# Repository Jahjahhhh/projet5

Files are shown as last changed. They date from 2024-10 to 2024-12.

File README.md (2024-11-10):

# Standing desk projet

```/projet5/table-2/```: KiCAD files<br>
```/projet/arduino/projet5```: Arduino files

### Hardware
- 2x 12VDC Linear Actuators (12")
- ESP32 (To access the web and gather info for date, time, weather)
- Dual H-Bridge motor driver (each linear actuator pulls 5 A continuous)
- LED strip (5V Adressable LEDs)
- USB charging hub (2x USB-A & 1x USB-C)
- Ultrasonic sensor to detect when you go from standing to sitting
- MPU6050 (3 axis gyro and accelerometer) to measure the flatness of the table (in case the linear actuators are out of sync)
- 4 Debounced push buttons
- 1 SPDT toggle switch to control linear actuators (ON - OFF - ON)
- 1.8" OLED SPI display

### Schematic
![alt text](https://github.com/Jahjahhhh/projet5/blob/main/schematic.png?raw=true)
<br>

### PCB
![alt text](https://github.com/Jahjahhhh/projet5/blob/main/pcb.png?raw=true)

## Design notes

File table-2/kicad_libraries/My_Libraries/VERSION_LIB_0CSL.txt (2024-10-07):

VERSION 124
de 0CSL_D1_V1  POUR KiCad V6

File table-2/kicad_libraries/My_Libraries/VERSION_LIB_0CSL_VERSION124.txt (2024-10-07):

Ce fichier indique par son nom même dans quelle version de quelle librairie il se trouve.

André Gauthier 6 octobre 2023 pour la version 124 LA DERNIERE DE A 2023!

   La version 86 est le première version permettant 
          de réaliser le SHIELD Versions 2022 et 2023.

   La version 80 est la première version des lib du CÉGEP pour KiCadV6
     nombreuses corrections de courtyard et de pointeurs pour modeles 3D   

L'utilité de ce fichier est de savoir quelle version de la librairie est la dernière installée.

Ce fichier est utilisé de concert avec le fichier
VERSION_LIB_0CSL.TXT  qui pour sa part contient le numéro de version.

Si on a copié de multiples versions de la librairie au même endroit, comme on doit normalement 
le faire pour avoir les nouvelles pièces du cours de projet, le dernier chiffre
apparent dans le nom de ce fichier doit être la dernière version installée
et on devrait retrouver cette valeur dans le fichier
VERSION_LIB_0CSL.TXT

Cette maniére de faire a été inspirée le 12 septembre 2020 par Madame Sydney Athans qui souhaitait 
trouver une méthode de savoir quelle était la librairie installée.

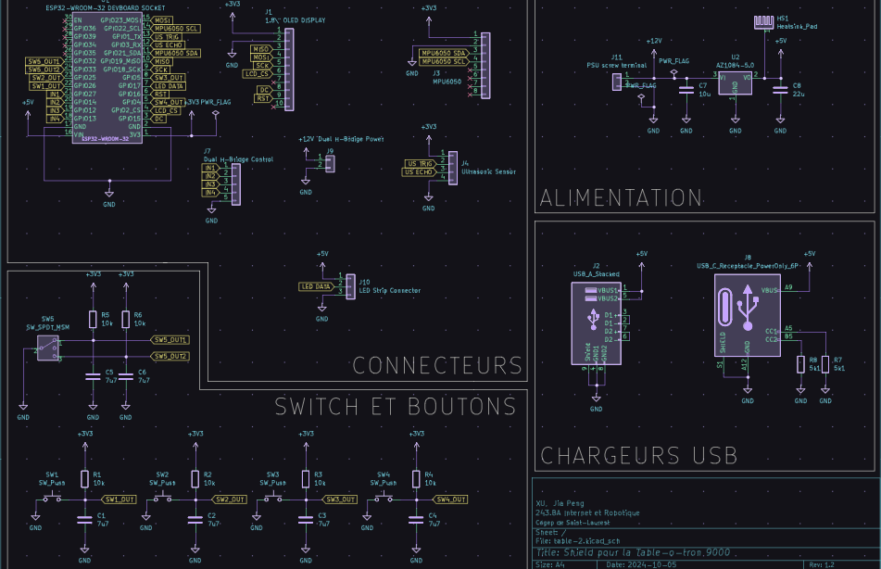
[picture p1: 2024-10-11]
schematic.png

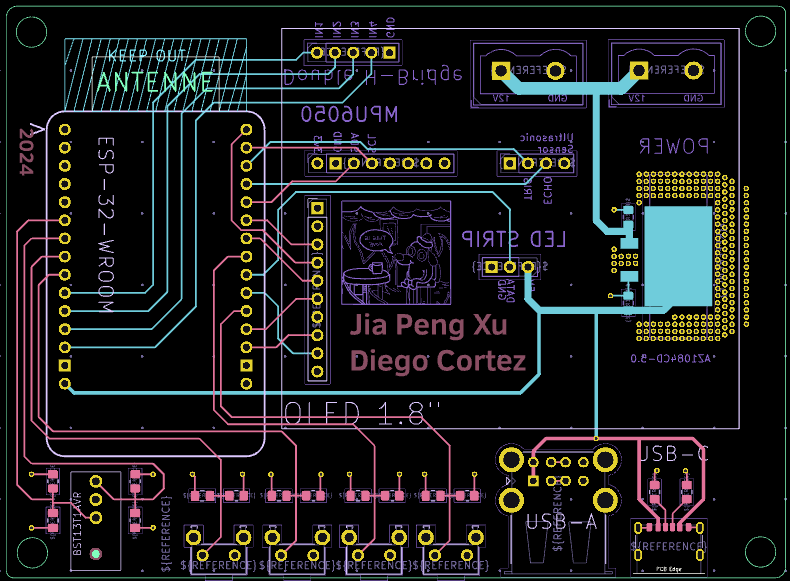
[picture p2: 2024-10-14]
pcb.png

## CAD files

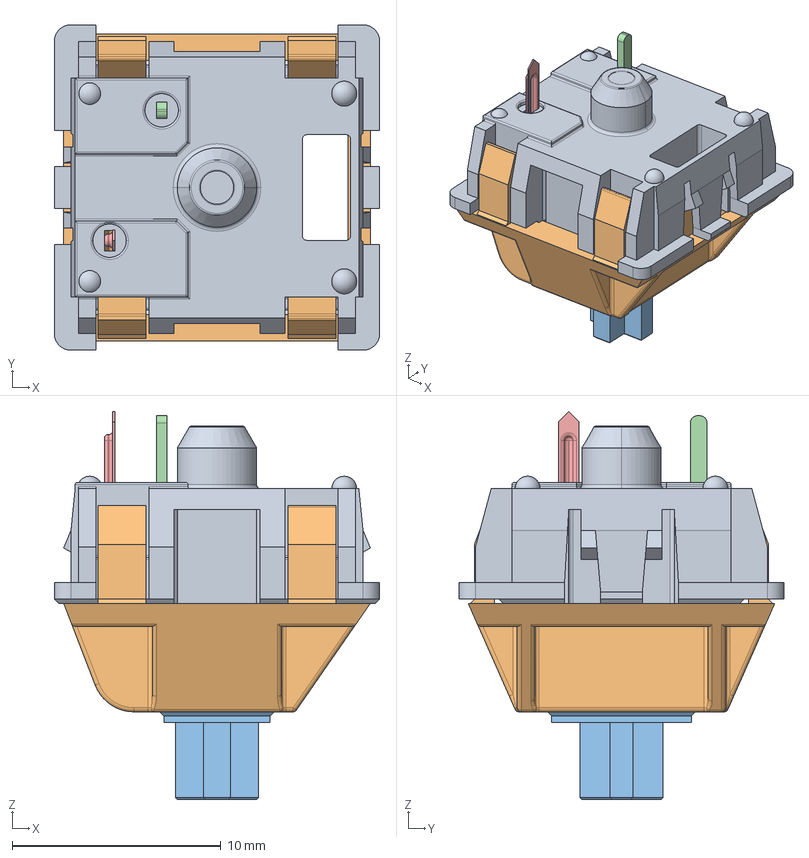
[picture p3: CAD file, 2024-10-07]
table-2/kicad_libraries/My_Libraries/CHERRY_asm_PLATE.stp
15.6 x 15.6 x 18.6 mm
MX_DOWN
MX_UP
UP_MX
MX_PIN
MX_SPRING
MX_CLICK

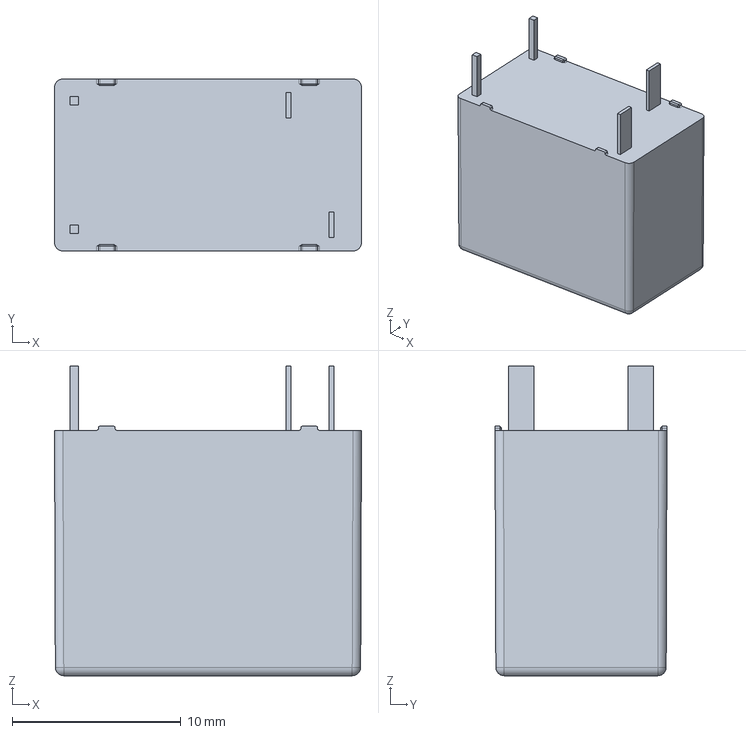
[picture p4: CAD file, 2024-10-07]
table-2/kicad_libraries/My_Libraries/c-1-2071556-1-a-3d.stp
18.2 x 10.2 x 18.4 mm

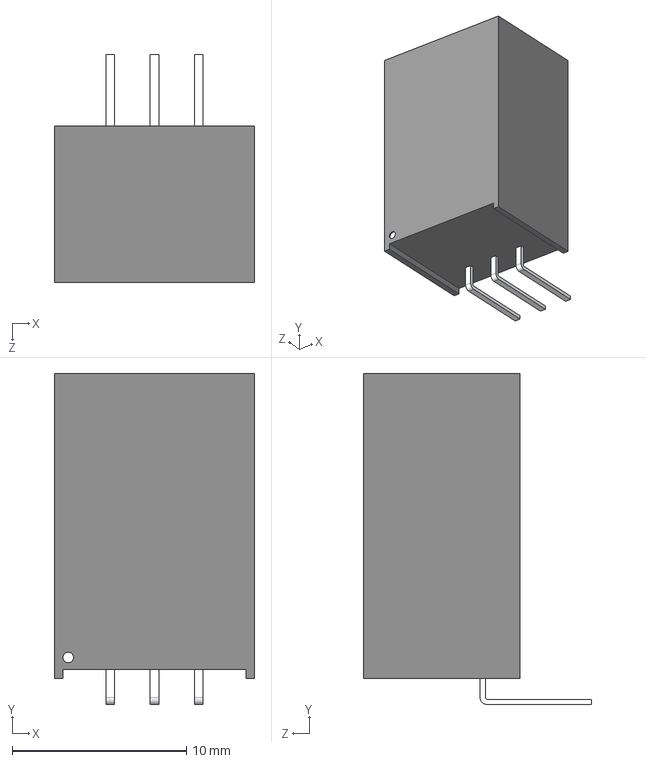
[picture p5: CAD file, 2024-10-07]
table-2/kicad_libraries/My_Libraries/CUI_V7805-1000R.step
11.5 x 19.0 x 13.1 mm

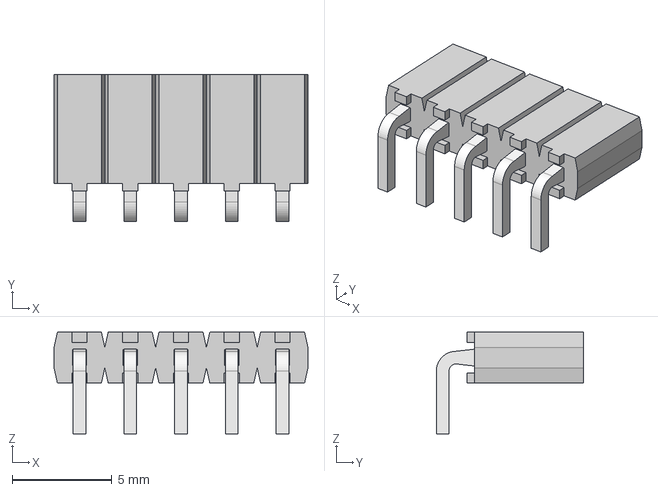
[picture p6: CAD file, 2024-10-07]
table-2/kicad_libraries/My_Libraries/Header_cassable_5Short_pins__simpleAG2.step
12.7 x 7.37 x 5.08 mm
_SSA-132-W-T-RA_t
_SSA-132-W-T-RA_p

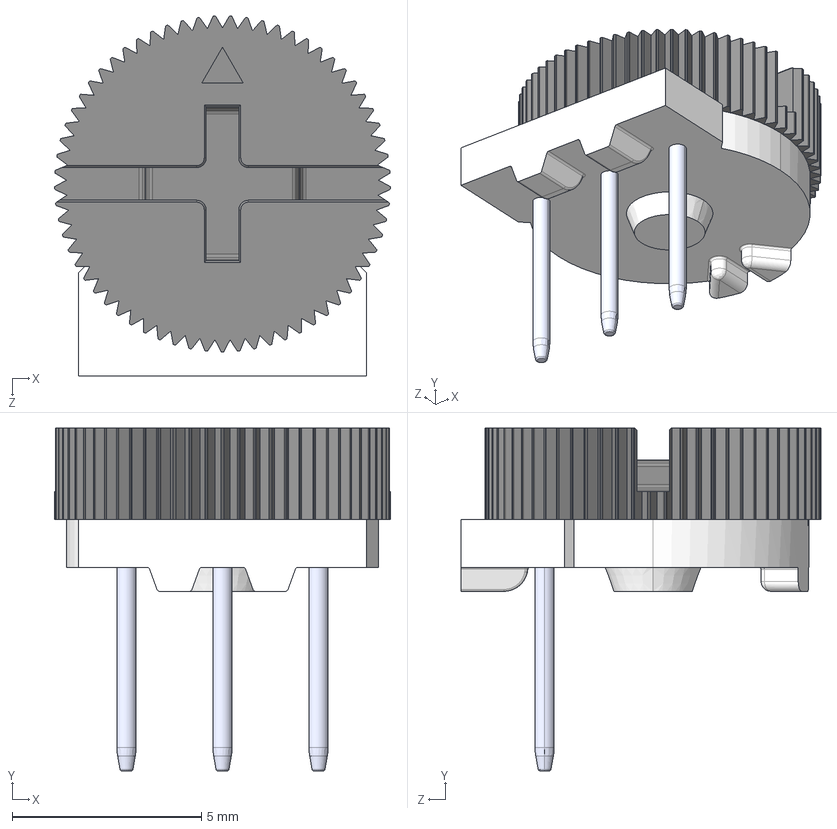
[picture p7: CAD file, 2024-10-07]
table-2/kicad_libraries/My_Libraries/POT_3352T-1-103LF.STEP
8.89 x 9.07 x 9.52 mm

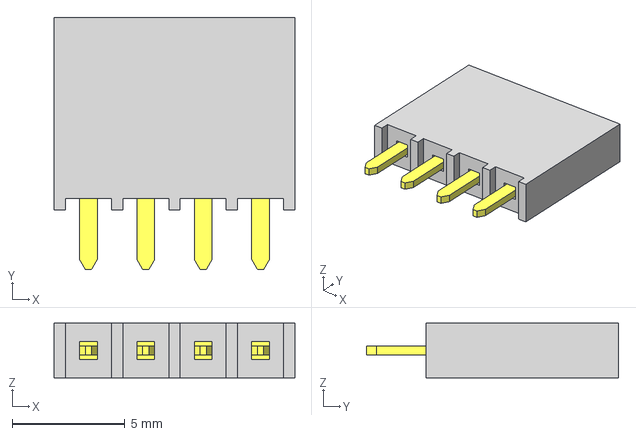
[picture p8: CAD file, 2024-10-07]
table-2/kicad_libraries/My_Libraries/Header4F_100mils.step
10.7 x 11.2 x 2.41 mm
_T1SSW-110-01-F-S
_P2SSW-110-01-F-S

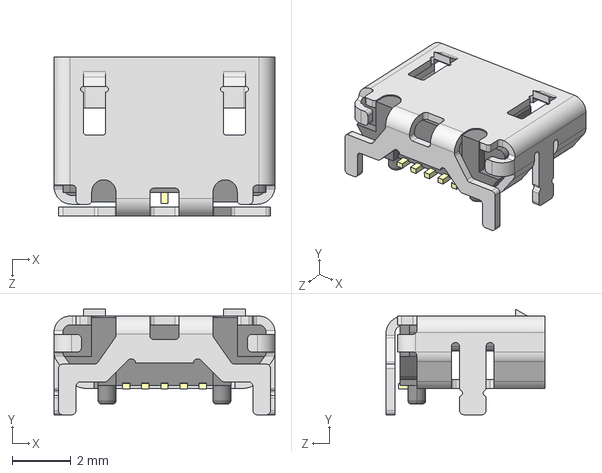
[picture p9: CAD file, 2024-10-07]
table-2/kicad_libraries/My_Libraries/KMMX-BSMT35S-BTR_A.STEP
7.50 x 3.58 x 5.40 mm

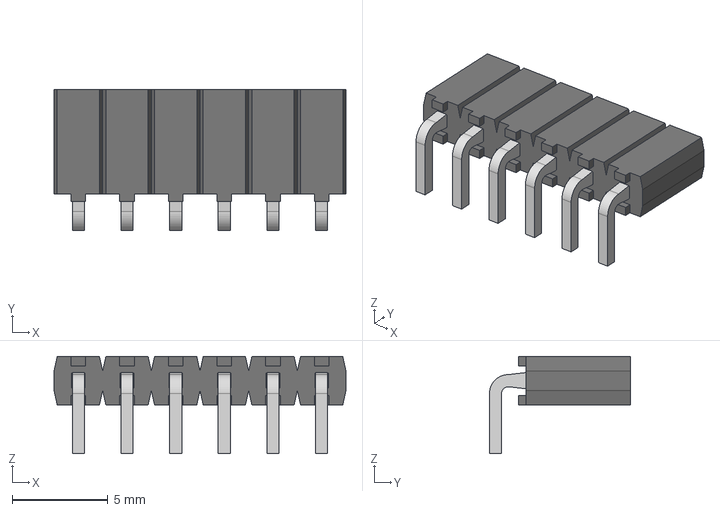
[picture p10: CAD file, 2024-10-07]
table-2/kicad_libraries/My_Libraries/Header_Cassable_6Short-pins_AG3.step
15.2 x 7.37 x 5.08 mm
_SSA-132-W-T-RA_t
_SSA-132-W-T-RA_p

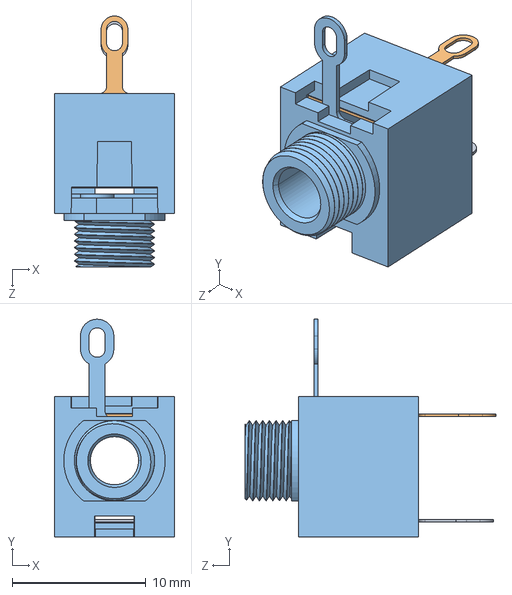
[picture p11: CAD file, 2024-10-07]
table-2/kicad_libraries/My_Libraries/KYCON3501.STEP
9.00 x 16.3 x 18.8 mm

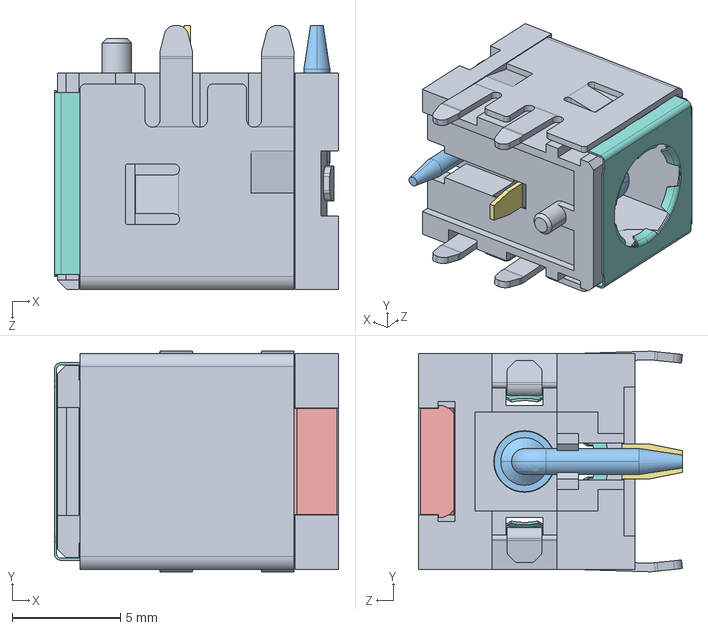
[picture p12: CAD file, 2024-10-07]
table-2/kicad_libraries/My_Libraries/CUI_DEVICES_PJ-082BH.step
13.1 x 10.2 x 12.2 mm

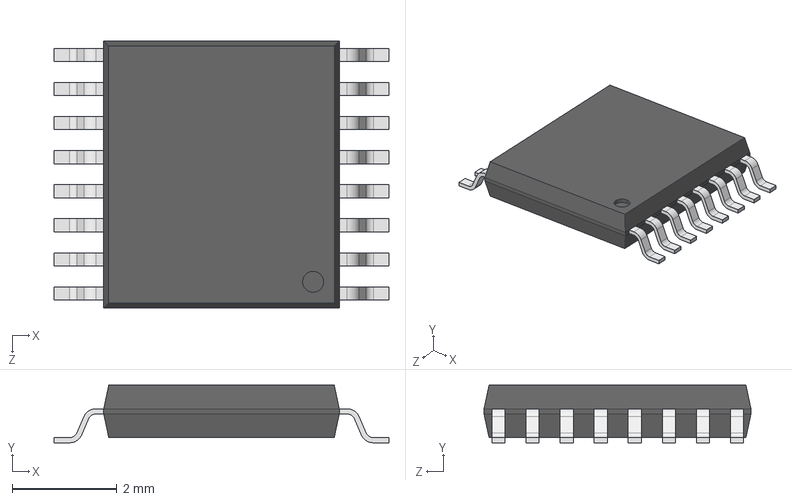
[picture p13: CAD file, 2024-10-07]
table-2/kicad_libraries/My_Libraries/TSSOP-16 5_1x4_4.STEP
6.40 x 1.10 x 5.10 mm
pin_TSSOP_tssop_1 x 16
body_TSSOP_TSSOP_5.1x4.5_1

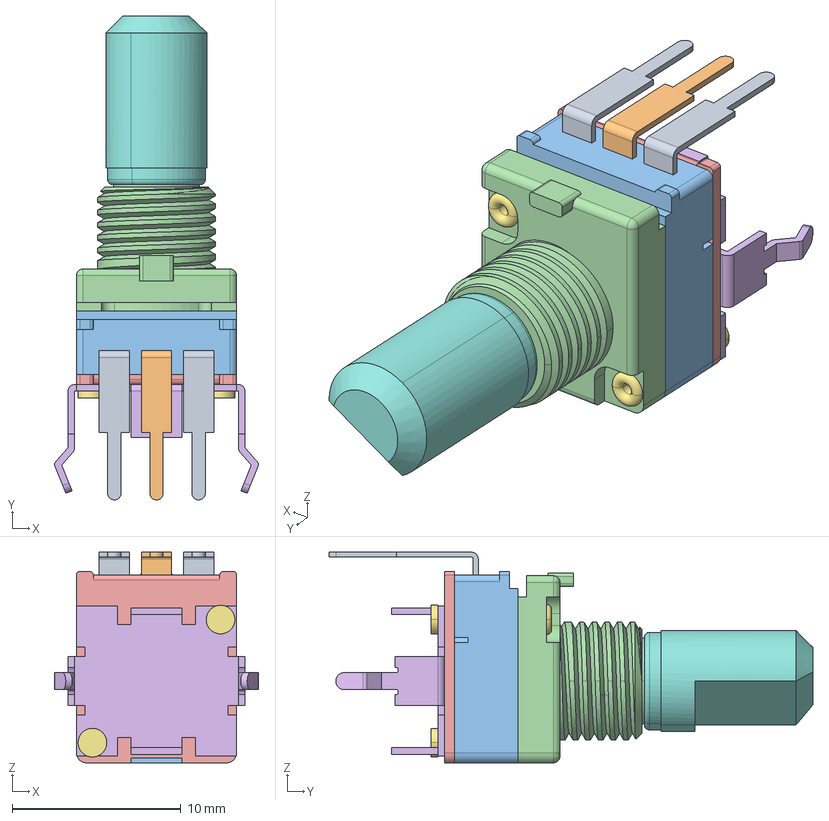
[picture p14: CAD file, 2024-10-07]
table-2/kicad_libraries/My_Libraries/P0915N-FC15AR50K.stp
12.1 x 28.7 x 12.5 mm

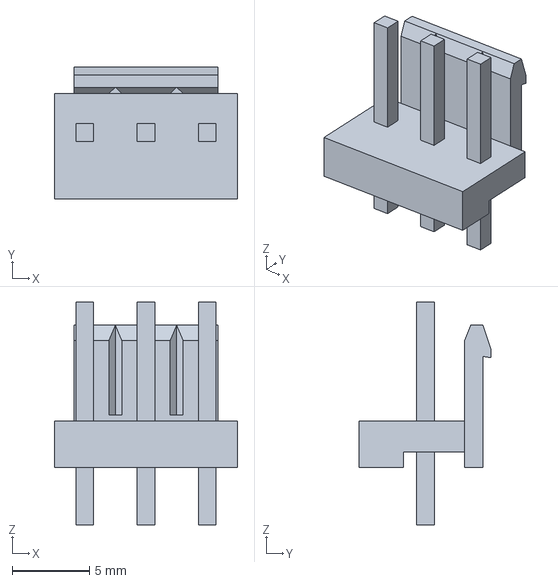
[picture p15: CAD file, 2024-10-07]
table-2/kicad_libraries/My_Libraries/1-1318300-3.stp
11.8 x 8.50 x 14.4 mm

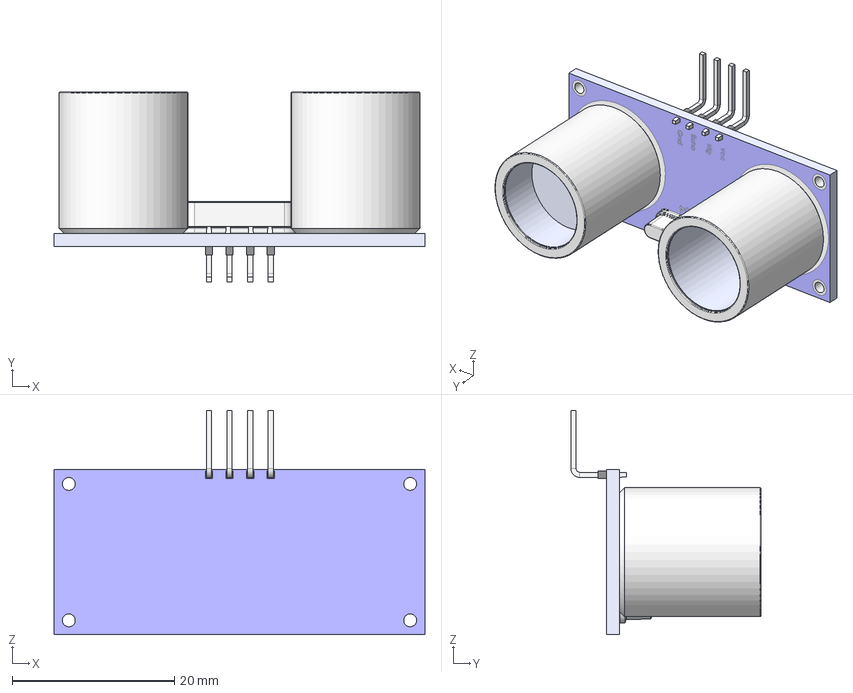
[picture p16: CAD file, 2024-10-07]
table-2/kicad_libraries/My_Libraries/HC_SR04_AG.step
45.7 x 23.4 x 27.6 mm

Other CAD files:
table-2/kicad_libraries/My_Libraries/Header_cassable_4Short_pins__simpleAG2 v1.step
table-2/kicad_libraries/My_Libraries/SOT_223_5.STEP
table-2/kicad_libraries/My_Libraries/cree xlamp_xp_e.stl
table-2/kicad_libraries/My_Libraries/1-1318300-2.stp
table-2/kicad_libraries/My_Libraries/1-1825027-1_Bouton_Bleu v1.step
table-2/kicad_libraries/My_Libraries/10067847_001RLF.stp
table-2/kicad_libraries/My_Libraries/1301_9503_3.STEP
table-2/kicad_libraries/My_Libraries/2908-05WB-MGAG.step
table-2/kicad_libraries/My_Libraries/3006_MAX98357.step
table-2/kicad_libraries/My_Libraries/3214J.stp
table-2/kicad_libraries/My_Libraries/395430202.stp
table-2/kicad_libraries/My_Libraries/530480260.stp
table-2/kicad_libraries/My_Libraries/530480910.stp
table-2/kicad_libraries/My_Libraries/61201021621--3DModel-STEP-56544.STEP
table-2/kicad_libraries/My_Libraries/62684_502100AHLF_A.step
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

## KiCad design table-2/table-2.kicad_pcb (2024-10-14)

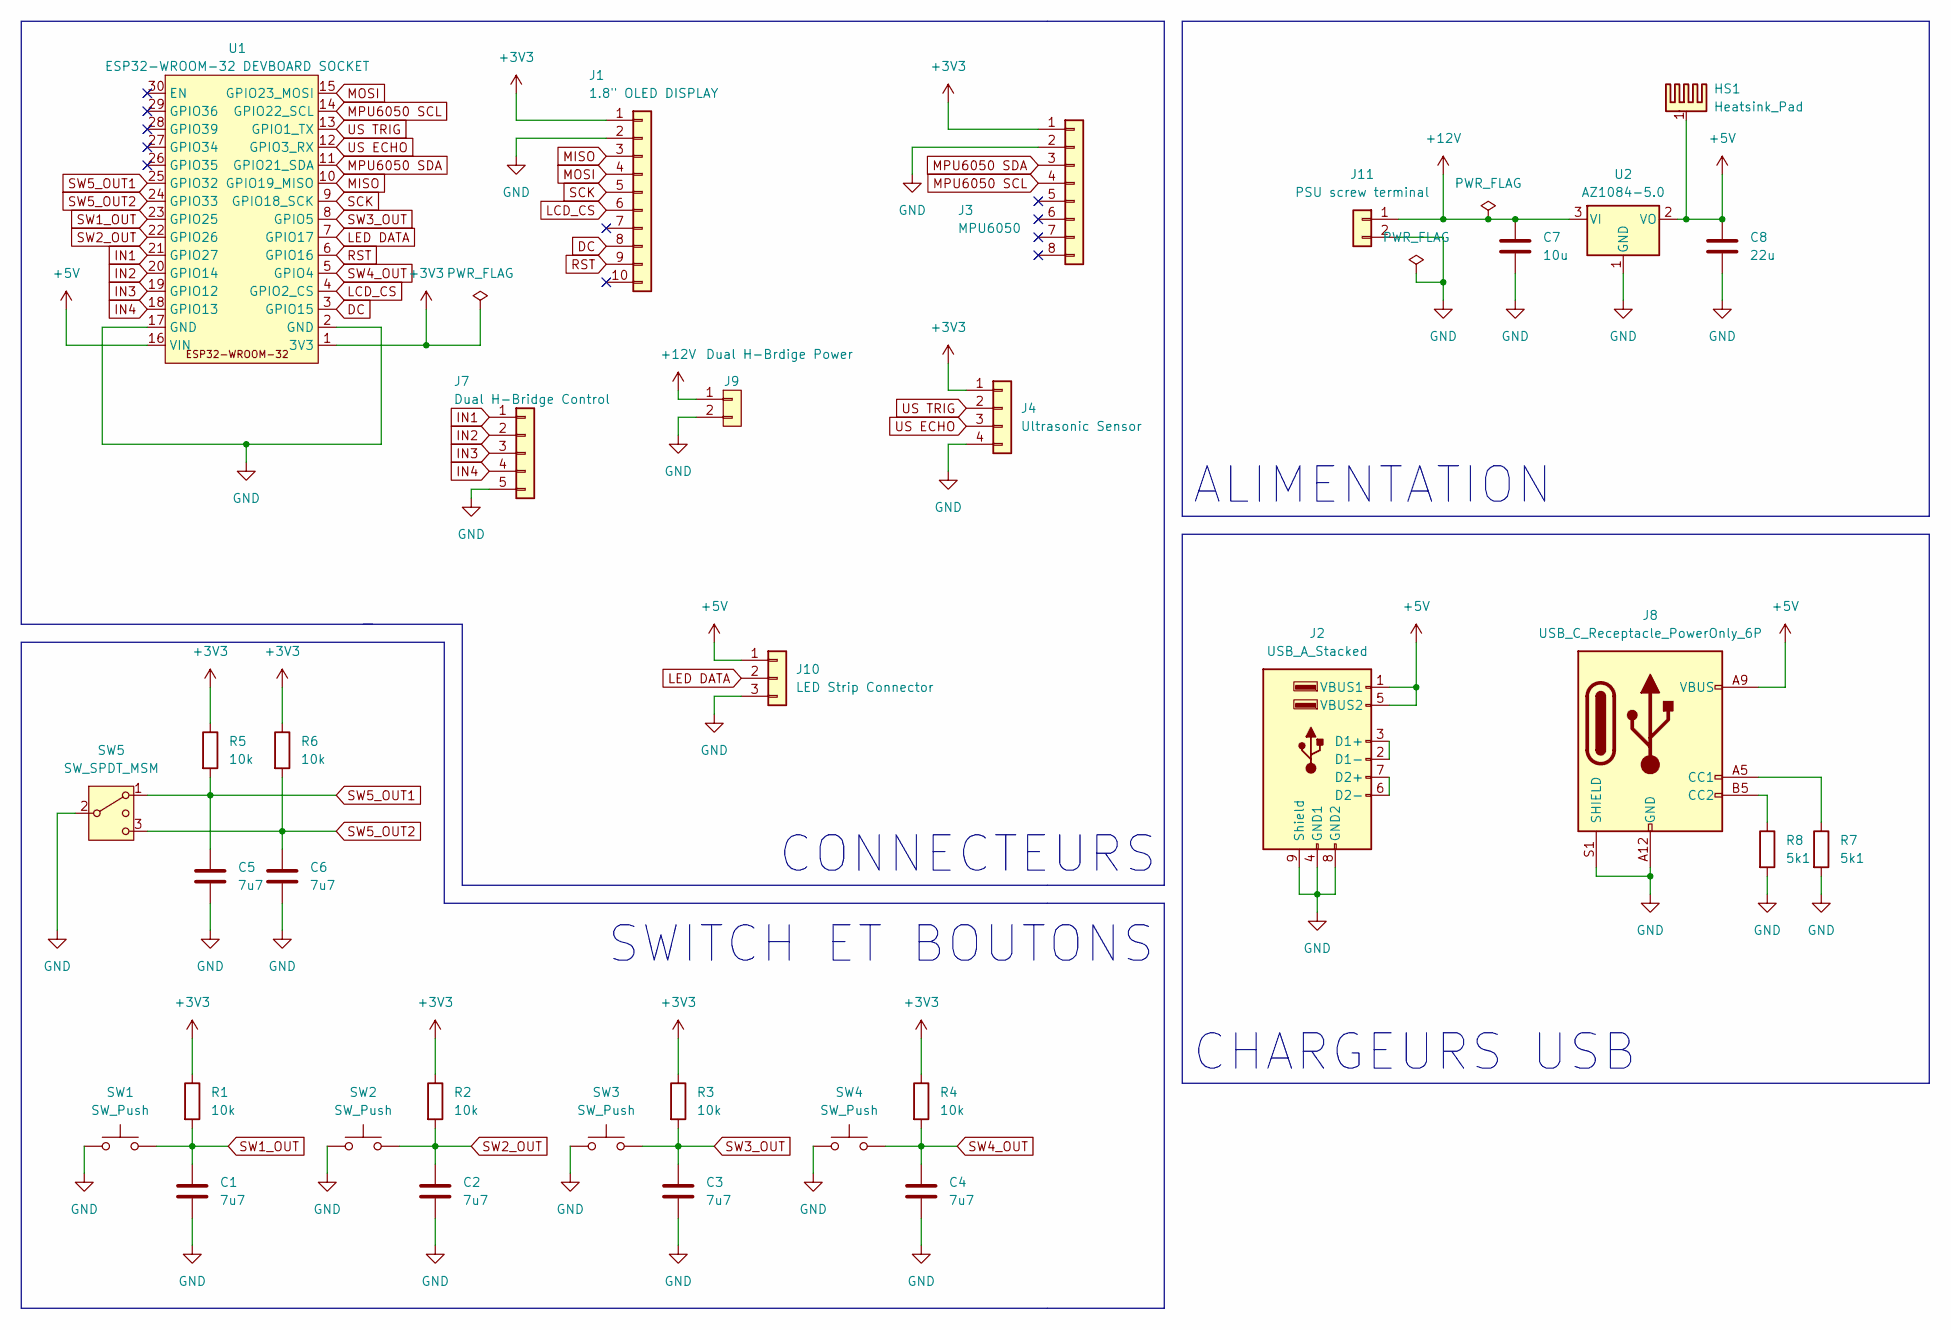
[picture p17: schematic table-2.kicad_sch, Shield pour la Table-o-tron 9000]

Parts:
C1, C2, C3, C4, C5, C6: 7u7; C_0805_2012Metric_Pad1.18x1.45mm_HandSolder
C7: 10u; C_0805_2012Metric_Pad1.18x1.45mm_HandSolder
C8: 22u; C_0805_2012Metric_Pad1.18x1.45mm_HandSolder
HS1: Heatsink_Pad; HEATSINK_573100D00000G
J1: 1.8" OLED DISPLAY; PinHeader_1x10_P2.54mm_Vertical
J2: USB_A_Stacked; USB_A_CUI_UJ2-ADH-TH_Horizontal_Stacked
J3: MPU6050; PinHeader_1x08_P2.54mm_Vertical
J4: Ultrasonic Sensor; PinHeader_1x04_P2.54mm_Vertical
J7: Dual H-Bridge Control; PinHeader_1x05_P2.54mm_Vertical
J8: USB_C_Receptacle_PowerOnly_6P; USB_C_Receptacle_GCT_USB4125-xx-x-0190_6P_TopMnt_Horizontal
J9: Dual H-Brdige Power; TerminalBlock_Wuerth_691311400102_P7.62mm; Manufacturer Part Number 0530480260
J10: LED Strip Connector; PinHeader_1x03_P2.54mm_Vertical
J11: PSU screw terminal; TerminalBlock_Wuerth_691311400102_P7.62mm
R1, R2, R3, R4, R5, R6: 10k; R_0805_2012Metric_Pad1.20x1.40mm_HandSolder
R7, R8: 5k1; R_0805_2012Metric_Pad1.20x1.40mm_HandSolder
SW1, SW2, SW3, SW4: SW_Push; Tactile_90_TE
SW5: SW_SPDT_MSM; BST13T1AVR
U1: ESP32-WROOM-32 DEVBOARD SOCKET; ESP32_WROOM_32
U2: AZ1084-5.0; AZ1084CD-5.0TRG1

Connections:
+3V3: J1.1, J3.1, J4.1, R1.1, R2.1, R3.1, R4.1, R5.1, R6.1, U1.1 (3V3)
+5V: C8.1, HS1.1, J2.1 (VBUS1), J2.5 (VBUS2), J8.A9 (VBUS), J8.B9 (VBUS), J10.1, U1.16 (VIN), U2.2 (VO)
+12V: C7.1, J9.1, J11.1, U2.3 (VI)
DC: J1.8, U1.3 (GPIO15)
GND: C1.2, C2.2, C3.2, C4.2, C5.2, C6.2, C7.2, C8.2, J1.2, J2.4 (GND1), J2.8 (GND2), J2.9 (Shield), J3.2, J4.4, J7.5, J8.A12 (GND), J8.B12 (GND), J8.S1 (SHIELD), J9.2, J10.3, J11.2, R7.2, R8.2, SW1.1, SW2.1, SW3.1, SW4.1, SW5.2 (3), U1.2 (GND), U1.17 (GND), U2.1 (GND)
IN1: J7.1, U1.21 (GPIO27)
IN2: J7.2, U1.20 (GPIO14)
IN3: J7.3, U1.19 (GPIO12)
IN4: J7.4, U1.18 (GPIO13)
LCD_CS: J1.6, U1.4 (GPIO2_CS)
LED DATA: J10.2, U1.7 (GPIO17)
MISO: J1.3, U1.10 (GPIO19_MISO)
MOSI: J1.4, U1.15 (GPIO23_MOSI)
MPU6050 SCL: J3.4, U1.14 (GPIO22_SCL)
MPU6050 SDA: J3.3, U1.11 (GPIO21_SDA)
unnamed: J2.2 (D1-), J2.3 (D1+)
unnamed: J2.6 (D2-), J2.7 (D2+)
unnamed: J8.A5 (CC1), R7.1
unnamed: J8.B5 (CC2), R8.1
RST: J1.9, U1.6 (GPIO16)
SCK: J1.5, U1.9 (GPIO18_SCK)
SW1_OUT: C1.1, R1.2, SW1.2, U1.23 (GPIO25)
SW2_OUT: C2.1, R2.2, SW2.2, U1.22 (GPIO26)
SW3_OUT: C3.1, R3.2, SW3.2, U1.8 (GPIO5)
SW4_OUT: C4.1, R4.2, SW4.2, U1.5 (GPIO4)
SW5_OUT1: C5.1, R5.2, SW5.1, U1.25 (GPIO32)
SW5_OUT2: C6.1, R6.2, SW5.3 (4), U1.24 (GPIO33)
US ECHO: J4.3, U1.12 (GPIO3_RX)
US TRIG: J4.2, U1.13 (GPIO1_TX)

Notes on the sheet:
CONNECTEURS
CHARGEURS USB
SWITCH ET BOUTONS
ALIMENTATION

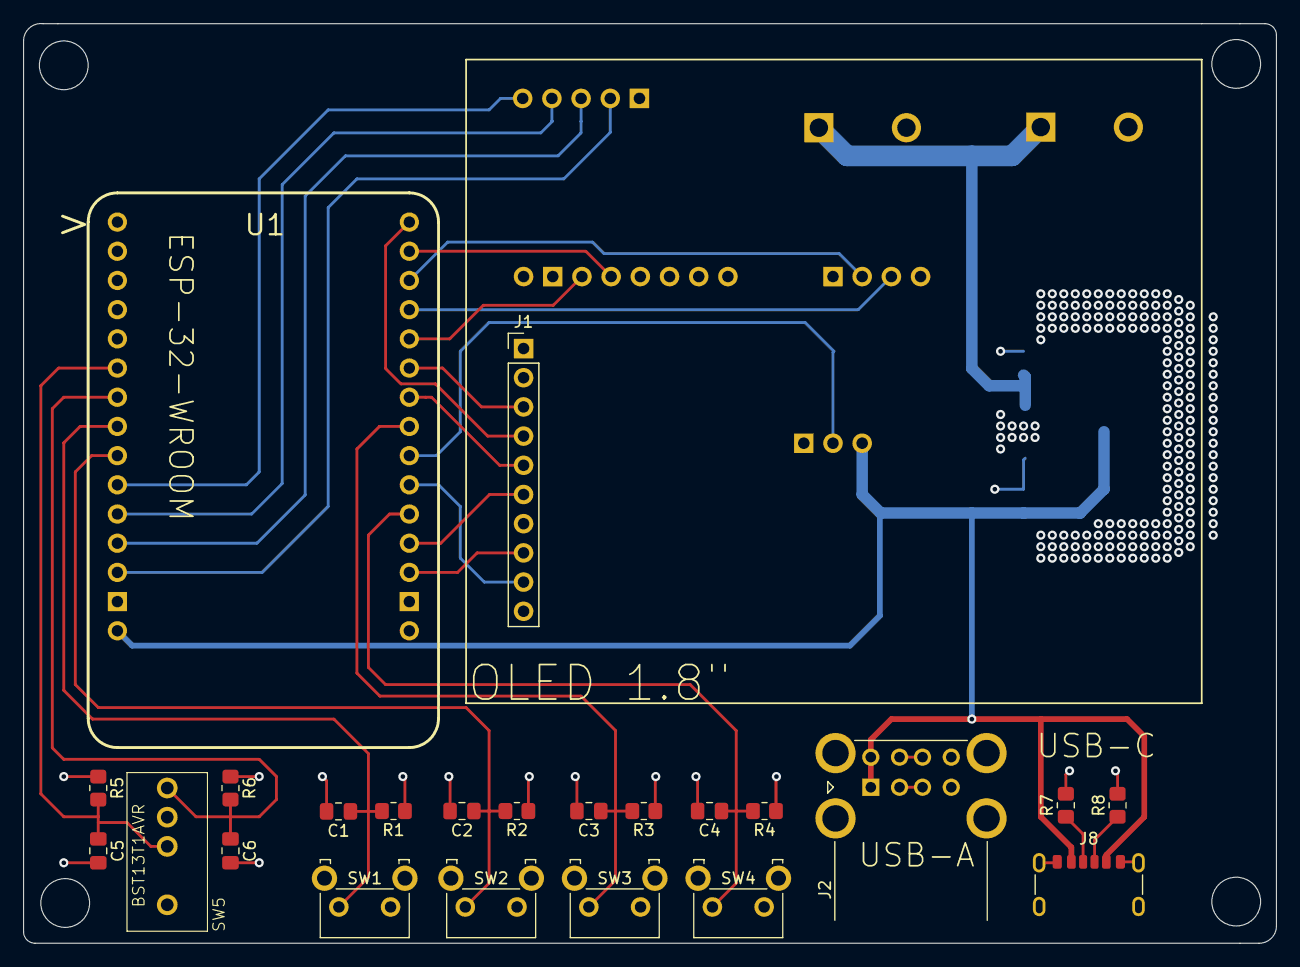
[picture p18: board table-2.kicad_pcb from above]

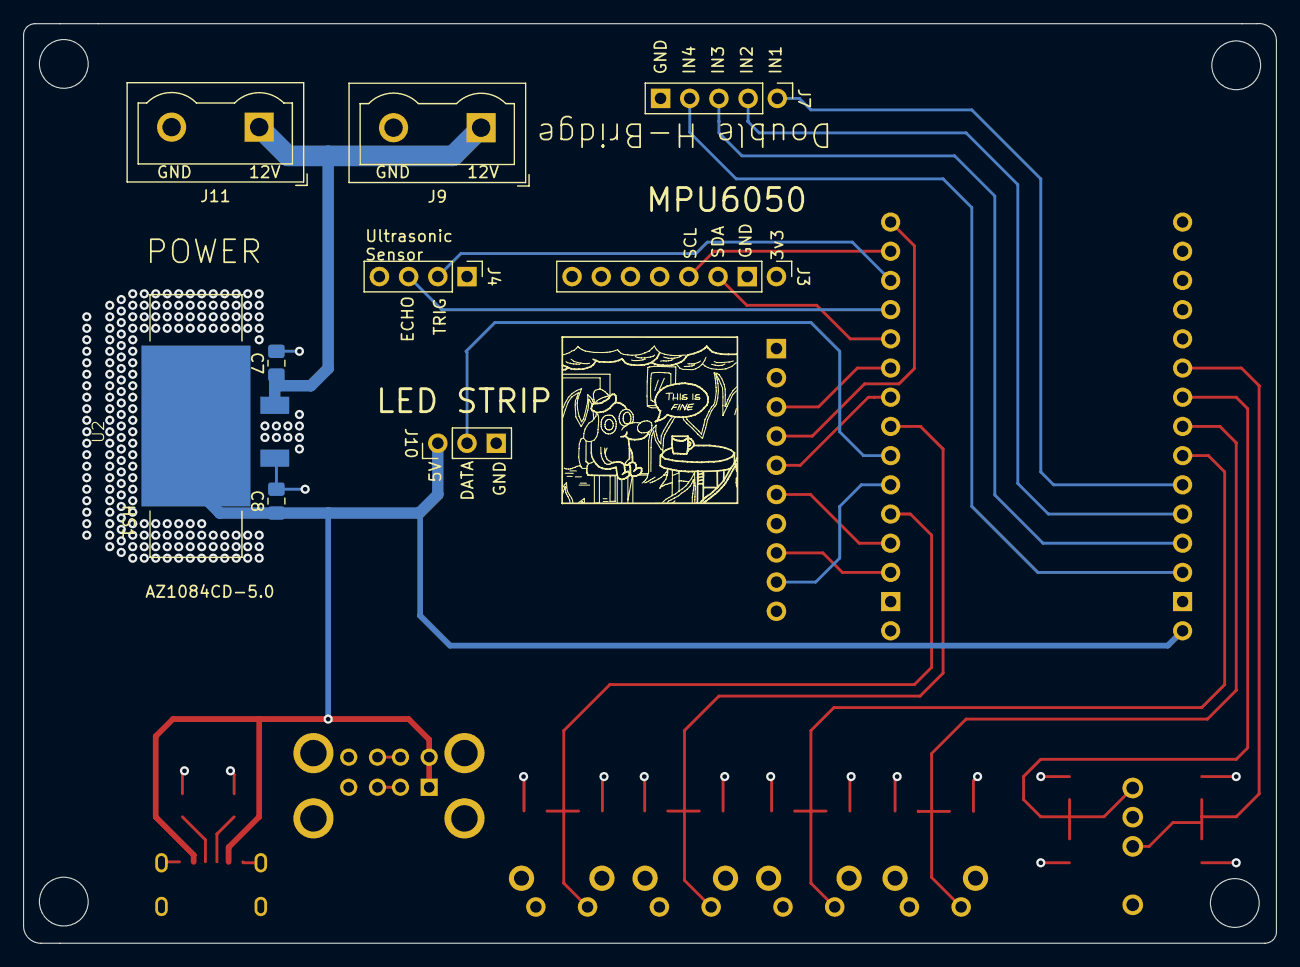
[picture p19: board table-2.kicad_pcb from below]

Board: 4 copper layers, 109.0 x 80.0 mm, 33 parts (10 on the bottom side), 29 nets.

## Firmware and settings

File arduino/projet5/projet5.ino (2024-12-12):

#include <Adafruit_GFX.h>     // Core graphics library
#include <Adafruit_ST7735.h>  // Hardware-specific library for ST7735
#include <SPI.h>
#include <WiFi.h>
#include <Time.h>
#include <HTTPClient.h>
#include <ArduinoJson.h>

#include "projet5-setup.h"

#include "PIN_DEFINITIONS.h"
#include "CONSTANTS.h"

Adafruit_ST7735 tft = Adafruit_ST7735(TFT_CS, TFT_DC, TFT_RST);

float p = 3.1415926;

void setup(void) {
  tft.initR(INITR_GREENTAB);  // Adds offset to screen, required for Waveshare displays
  tft.setRotation(1);         // Rotate display by 90 degrees
  delay(1000);
  esp_setup();
  tft.fillScreen(ST77XX_BLACK);
  drawtext("ESP32 SETUP DONE", ST77XX_GREEN, 20, 50);
  wifi_setup();
  tft.fillScreen(ST77XX_BLACK);
  drawtext("WIFI SETUP DONE", ST77XX_GREEN, 20, 50);
  ntp_setup();
  tft.fillScreen(ST77XX_BLACK);
  drawtext("NTP SETUP DONE", ST77XX_GREEN, 20, 50);
}

void loop() {
  print_local_time();
  delay(5000);
  get_weather();
  delay(10000);
}

void adjust_height() {
  tft.fillScreen(ST77XX_BLACK);
  drawtext("PRESS S4 TO CONTINUE", ST77XX_GREEN, 20, 50);
  while (digitalRead(SW4_PIN))
    ;
  delay(50);
  while (!digitalRead(SW4_PIN))
    ;
  delay(50);

  tft.fillScreen(ST77XX_BLACK);
  drawtext("PRESS S4 TO EXIT", ST77XX_GREEN, 20, 50);
  while (digitalRead(SW4_PIN)) {
    if (!digitalRead(SW5_PIN_H)) {
      tft.fillScreen(ST77XX_BLACK);
      drawtext("MOTORS EXTENDING!", ST77XX_GREEN, 20, 50);
      while (!digitalRead(SW5_PIN_H)) {
        extend1();
        extend2();
      }
    }
    if (digitalRead(SW5_PIN_H) && digitalRead(SW5_PIN_L)) {
      tft.fillScreen(ST77XX_BLACK);
      drawtext("MOTORS OFF!", ST77XX_WHITE, 20, 50);
      while (digitalRead(SW5_PIN_H) && digitalRead(SW5_PIN_L)) {
        stop();
      }
    }
    if (!digitalRead(SW5_PIN_L)) {
      tft.fillScreen(ST77XX_BLACK);
      drawtext("MOTORS RETRACTING!", ST77XX_GREEN, 20, 50);
      while (!digitalRead(SW5_PIN_L)) {
        retract1();
        retract2();
      }
    }
  }
}

void get_weather() {
  if (WiFi.status() == WL_CONNECTED) {
    HTTPClient http;
    String url = String("http://api.weatherapi.com/v1/current.json?key=") + weather_api_key + "&q=" + city;

    http.begin(url);                    // Specify the URL
    int httpResponseCode = http.GET();  // Make the request

    if (httpResponseCode > 0) {
      String payload = http.getString();  // Get the response
      // Serial.println("Response:");
      // Serial.println(payload);

      // Parse JSON response
      StaticJsonDocument<1024> doc;
      deserializeJson(doc, payload);

      // Extract specific data
      const char* location = doc["location"]["name"];
      float tempC = doc["current"]["temp_c"];
      const char* condition = doc["current"]["condition"]["text"];

      char temp_str[16]; 
      sprintf(temp_str, "%,1f°C", tempC);

      // Print weather data
      tft.fillScreen(ST77XX_BLACK);
      drawtext("Weather Data:", ST77XX_WHITE, 0, 0);
      drawtext("Location: ", ST77XX_WHITE, 0, 10);
      drawtext(location, ST77XX_WHITE, 0, 20);
      drawtext("Temperature: ", ST77XX_WHITE, 0, 30);
      drawtext(temp_str, ST77XX_WHITE, 0, 40);
      drawtext("Condition: ", ST77XX_WHITE, 0, 50);
      drawtext(condition, ST77XX_WHITE, 0, 60);
    } else {
      char http_code_str[16];
      sprintf(http_code_str, "Error code: %d", httpResponseCode);
      tft.fillScreen(ST77XX_BLACK);
      drawtext("Error on HTTP request: ", ST77XX_WHITE, 0, 0);
      drawtext(http_code_str, ST77XX_WHITE, 0, 10);
    }
    http.end();  // Close connection
  }
}

void extend1() {
  digitalWrite(IN1, LOW);
  digitalWrite(IN2, HIGH);
}

void extend2() {
  digitalWrite(IN3, LOW);
  digitalWrite(IN4, HIGH);
}

void retract1() {
  digitalWrite(IN1, HIGH);
  digitalWrite(IN2, LOW);
}

void retract2() {
  digitalWrite(IN3, HIGH);
  digitalWrite(IN4, LOW);
}

void stop() {
  digitalWrite(IN1, LOW);
  digitalWrite(IN2, LOW);
  digitalWrite(IN3, LOW);
  digitalWrite(IN4, LOW);
}

void drawtext(const char* text, uint16_t color, int16_t x, int16_t y) {
  tft.setCursor(x, y);
  tft.setTextColor(color);
  tft.setTextWrap(false);
  tft.print(text);
}

void print_local_time() {
  struct tm timeinfo;
  if (!getLocalTime(&timeinfo)) {
    tft.fillScreen(ST77XX_BLACK);
    drawtext("Failed to obtain time!", ST77XX_WHITE, 0, 0);
    return;
  }
  char time_str[64];
  char time_str2[64];
  strftime(time_str, sizeof(time_str), "%A, %B %d %Y", &timeinfo);
  strftime(time_str2, sizeof(time_str2), "%H:%M:%S", &timeinfo);
  tft.fillScreen(ST77XX_BLACK);
  drawtext(time_str, ST77XX_WHITE, 0, 0);
  drawtext(time_str, ST77XX_WHITE, 0, 10);
}

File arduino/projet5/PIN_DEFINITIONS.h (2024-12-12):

/*
  LCD PINS
*/
#define TFT_CS        2
#define TFT_RST       16 // Or set to -1 and connect to Arduino RESET pin
#define TFT_DC        15

/*
  PUSH BUTTON AND SWITCH PINS
*/
#define SW1_PIN 25
#define SW2_PIN 26
#define SW3_PIN 5
#define SW4_PIN 4
#define SW5_PIN_H 32
#define SW5_PIN_L 33

/*
  DOUBLE H-BRIDGE PINS
*/
#define IN1 27
#define IN2 14
#define IN3 12
#define IN4 13
#define PWM1 3
#define PWM2 1
/*
  MPU6050 PINS
*/
#define MPU_SDA 21
#define MPU_SCL 22

/*
  ULTRASONIC SENSOR PINS
*/
#define TRIG 1
#define ECHO 3

/*
  LED STRIP DATA PIN
*/
#define LED_DATA 17

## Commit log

2024-10-05 added an image for the schematic
2024-10-07 added footprints, changed volt reg, changed toggle switch, and more
    [1-1318300-2.stp, 1-1318300-3.stp, 1-1825027-1_Bouton_Bleu v1.step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]
2024-10-08 updated schematic image
2024-10-08 Update README.md
    changed my toggle switch from a dp3t to a spdt (on/off/on) in the schematic & footprint editor
2024-10-11 pcb v1
    [table-2.kicad_pcb]
2024-10-11 added png of pcb
2024-10-11 updated schematic png
2024-10-14 forgot about the backside of the pcb. this is one much smaller and denser
    [table-2-B_Cu.gbl, table-2-B_Mask.gbs, table-2-B_Paste.gbp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]
2024-10-14 updated pcb image
